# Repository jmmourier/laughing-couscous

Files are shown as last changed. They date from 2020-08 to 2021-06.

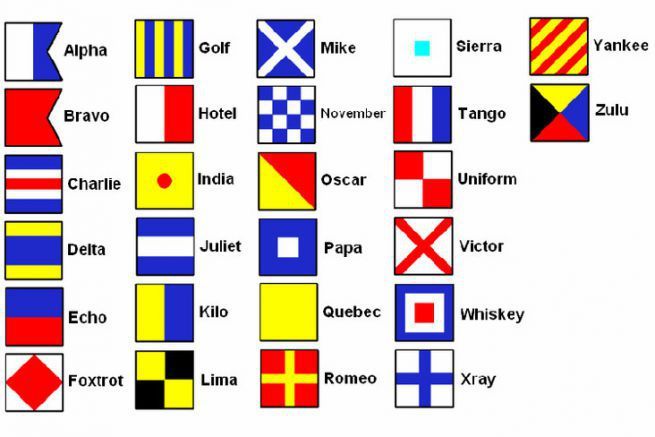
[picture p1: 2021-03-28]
documents/ima-pavillon-alphabet-27640.jpg

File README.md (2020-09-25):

# laughing-couscous

## Presentation   
Couscous is the robot to participate to the eurobot competition.

## Competition  
The robot evolve in a 3 by 2 m environment and perform several action including navigation, detection, recognition and action.
more info about the competition :   
[official website](https://www.eurobot.org/)  
[official rules](https://www.eurobot.org/images/2020/Eurobot2020_Rules_Cup_OFFICIAL_FR.pdf)  

## Team  

## More info
please visit the [wiki](https://github.com/jmmourier/laughing-couscous/wiki) for more info.

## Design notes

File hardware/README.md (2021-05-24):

# Hardware

Pin connections on pro micro : 

                  USB   
            ┌─────────────┐
    MD25 RX │TX        RAW│
    MD25 TX │RX        GND│
            │GND     RESET│
            │GND       VCC│
     I2C US │2-SDA      A3│
     I2C US │3-SCL      A2│
    Grabber │4          A1│
       Flag │5          A0│
            │6          15│
   Select 1 │7          14│Start button
            │8          16│Led R (HS)
   Select 3 │9          10│Led G
            └─────────────┘

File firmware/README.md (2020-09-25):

# Firmware

## introduction
The firmware is running on arduino pro micro.  

## compile and deploy 
using the arduino cli tool :  

    ./arduino-cli compile --fqbn arduino:avr:leonardo myProject
    ./arduino-cli upload -p /dev/ttyACM0 --fqbn arduino:avr:leonardo myProject --log-level debug -v

more info on the [wiki](https://github.com/jmmourier/laughing-couscous/wiki/%5BTools%5D-Flashing-arduino)

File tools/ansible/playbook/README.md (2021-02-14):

# Intro

The goal of this document is to explain in detail every step to be able to deploy on the Raspberry pi zero.

Cross-compile has been added on a previous PR that provides an easy way between x86/ARM compilation. With that we can use Ansible to easily compile C++ sources, build the front end and deploy the result on the target. Ansible is obviously optional, every step described here can be one manually.

Ansible has been added to the docker file which means that every tool needed are now included in the image and no external dependency is required.

# Docker

if you haven't done it yet, make sure to build the docker image using the docker-compose.yml file (from `tools/docker` folder)

```
docker-compose up --build
```

# Connection

Using an other terminal use the following command to get inside the created container:

```
docker exec -it laughing-couscous /bin/bash
```

try to connect to your Raspberry pi with
`ssh pi@192.X.X.X`
If you can connect then you're good to go for the next steps.

# Setting the environment before deploying to the target

This step has be done the first time only. It will generate a file with your credential (make sure they are not sooooo secret). Still using the terminal inside the docker, execute the following command with your credentials from `ansible/` folder:

```
ansible-playbook playbook/setup_env.yml --extra-vars "PI_USERNAME=pi PI_IP=192.168.1.6 PI_PORT=22 PI_SSH_PASSWORD=raspberry"
```

# Last step, building sources and push the result on the target (Back AND front)

```
ansible-playbook playbook/build_and_run.yml
```

if you just want to compile and push the back side run:

```
ansible-playbook playbook/build_back_and_run.yml
```

DONE! Now open a browser and enter the Raspberry pi IP address.
Cheers

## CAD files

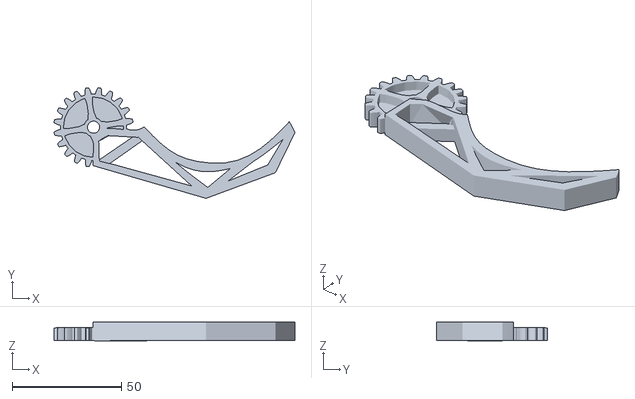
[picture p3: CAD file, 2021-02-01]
hardware/grabber/pinca4_v-2.stl
110.4 x 50.7 x 8.49

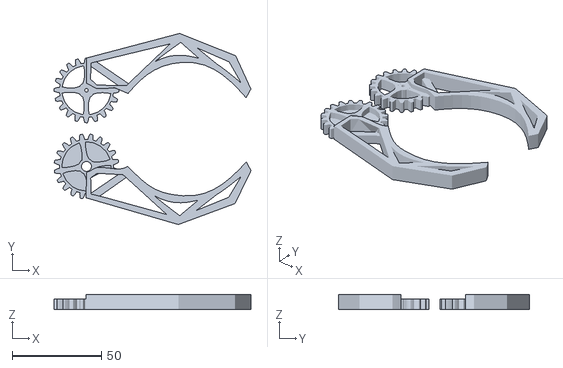
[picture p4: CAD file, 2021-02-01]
hardware/grabber/pinca4_v.STL
110.5 x 107.2 x 8.49

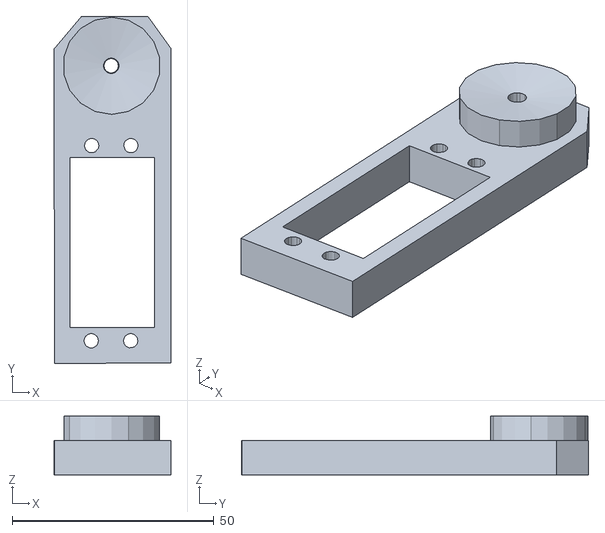
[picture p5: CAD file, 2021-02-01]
hardware/grabber/pincaServ1.STL
28.9 x 85.9 x 14.6

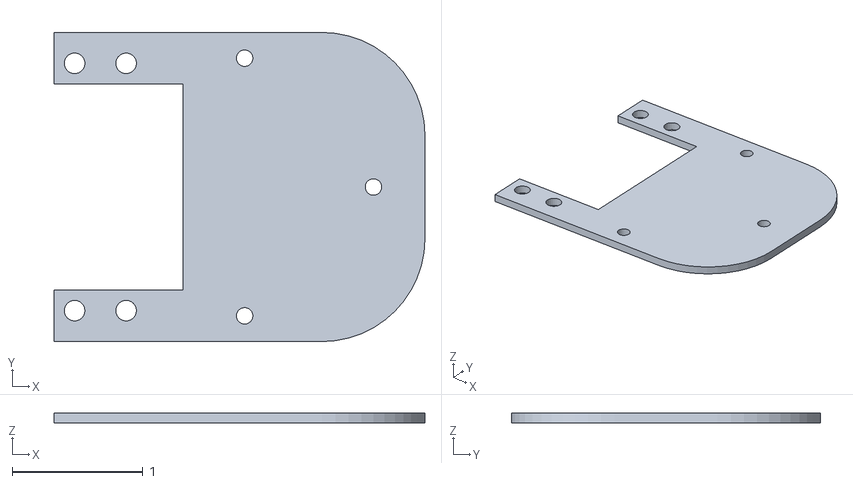
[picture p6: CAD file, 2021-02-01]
hardware/grabber/supportservomoteur1.stl
2.83 x 2.36 x 0.0787

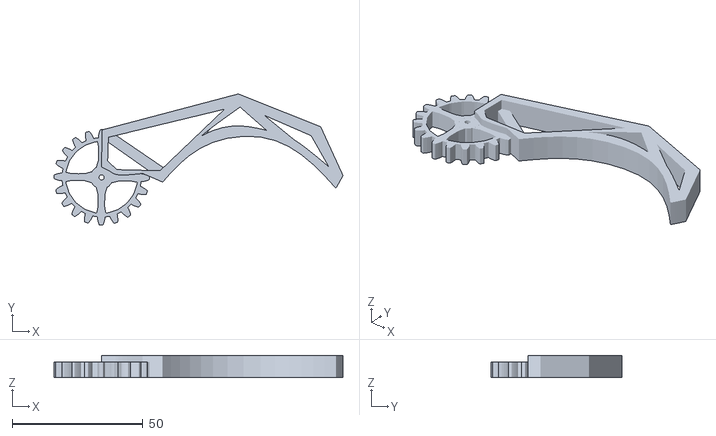
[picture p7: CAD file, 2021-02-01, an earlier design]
hardware/grabber/pinca4_v-1.stl
110.5 x 50.1 x 8.49

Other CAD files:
hardware/grabber/supportservomoteur1.skp

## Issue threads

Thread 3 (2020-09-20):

perhaps useless brackets

devkgs, 2020-09-20:
In Hali.h, line 16,
    virtual int getBatteryVoltage() {};

Why are { and } prensent?

Best wishes

jmmourier, 2020-09-20:
definitly useless, it's a residu when Hali was not the interface but the HalReal implementation, I will remove it next time.

jmmourier, 2020-09-22:
fixed

jmmourier, 2020-09-22:
Fixed

Closed 2020-09-22.

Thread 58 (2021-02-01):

encoder goes negative in forward and backward

devkgs, 2021-02-01:
[RobotController]robot controller callback onClientRequestSetSpeed1 1
encoder1:0 encoder2:0 posX:1 posY:1 angle:0
encoder1:-44 encoder2:-44 posX:0.923206 posY:1 angle:0
encoder1:-170 encoder2:-170 posX:0.703294 posY:1 angle:0

same when speed is -1, -1

jmmourier, 2021-02-01:
Let me check that on the real robot and I fix it

devkgs, 2021-02-09:
Question about arguments of setMd25Speed.

 setMd25Speed(speed_1, speed_2) :
- stop=127
- forward= values>127
- backward= values < 127

?

Closed 2021-02-13.

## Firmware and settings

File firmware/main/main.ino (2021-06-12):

#include "Flag/Flag.cpp"
#include "GameTimer/GameTimer.cpp"
#include "Grabber/Grabber.cpp"
#include "Leds/Leds.cpp"
#include "Md25/Md25.cpp"
#include "MessageParser/MessageParser.cpp"
#include "Switches/Switches.cpp"
#include "Srf02/Srf02.cpp"

int pin_grabber_ = 4;
Grabber grabber_(pin_grabber_);
unsigned long grabber_last_update_ = 0;
unsigned int grabber_timer_ = 300;  // ms

MessageParser message_parser_;
const int buffer_size = 80;
char buffer_[buffer_size];
int buffer_fullfillness = 0;

md25 md25_(Serial1);
unsigned long md25_last_update_ = 0;
unsigned int md25_timer_ = 300;  // ms

int pin_flag_ = 5;
Flag flag_(pin_flag_);
bool is_flag_up_ = false;
unsigned long flag_check_last_update_ = 0;
unsigned long flag_check_timer_ = 300;

int pin_switch_1_ = 7;
int pin_switch_2_ = 9;
Switches switches_(pin_switch_1_, pin_switch_2_);
unsigned long switches_last_update_ = 0;
unsigned long switches_timer_ = 300;

int pin_led_green_ = 10;
int pin_led_red_ = 16;
Leds leds_(pin_led_green_, pin_led_red_);
unsigned long leds_last_update_ = 0;
unsigned long leds_timer_ = 30;

GameTimer game_timer_;
bool is_game_finished = false;
unsigned long is_game_finished_last_update_ = 0;
unsigned long is_game_finished_timer_ = 300;

int pin_start_switch_ = 14;
unsigned long start_switch_last_update_ = 0;
unsigned long start_switch_timer_ = 100;

Srf02 srf02_;
unsigned long srf02_last_update_ = 0;
unsigned long srf02_timer_ = 30;
unsigned long srf02_send_value_last_update_ = 0;
unsigned long srf02_send_value_timer_ = 100;
bool obstacle_detected = false;


void setup() {
    Serial1.begin(38400);
    Serial.begin(9600);

    md25_.setMode(0);
    md25_.setAcceleration(2);
    md25_.resetEncoder();

    grabber_.init();
    delay(10);
    grabber_.open();

    flag_.init();
    delay(10);
    flag_.setFlag(flagDown);

    pinMode(pin_start_switch_,INPUT);

    leds_.setStatus(waiting);

    srf02_.init();
}

void loop() {

    readSerial();

    updateMd25();

    updateGrabber();

    updateFlag();

    checkStartButtonAndSendStatus();

    updateEndGame();

    checkSwitchesAndSendStatus();

    updateLeds();

    srf02Update();

}

void readSerial() {
    if (Serial.available()) {
        unsigned char input_char = Serial.read();
        buffer_[buffer_fullfillness] = input_char;
        buffer_fullfillness++;
        if (buffer_fullfillness >= buffer_size) {
            memset(buffer_, 0, sizeof(buffer_));
            buffer_fullfillness = 0;
        }
        if (input_char == message_parser_.getEndChar()) {
            CommandData command_data = message_parser_.parse(buffer_);
            HandleCommands(command_data);
            memset(buffer_, 0, sizeof(buffer_));
            buffer_fullfillness = 0;
        }
    }
}

void HandleCommands(CommandData command_data) {
    if (command_data.command_ == speedMotor1 &&
        is_game_finished == false &&
        obstacle_detected == false) {
        md25_.setSpeed(motor1, command_data.argument_);
    } else if (command_data.command_ == speedMotor2 &&
        is_game_finished == false && 
        obstacle_detected == false) {
        md25_.setSpeed(motor2, command_data.argument_);
    } else if (command_data.command_ == versionRevisionRequested) {
        md25_.updateRevision();
        delay(10);
        Serial.print("md25version:");
        Serial.print(md25_.getRevision());
        Serial.println(";");
    } else if (command_data.command_ == resetEncoder) {
        md25_.resetEncoder();
        delay(10);
    } else if (command_data.command_ == grabberPositionRequested &&
        is_game_finished == false) {
        if (command_data.argument_ == grabberOpened) {
            grabber_.open();
        } else if (command_data.argument_ == grabberClosed) {
            grabber_.close();
        }
    }
}

void updateMd25(){
    if (millis() - md25_last_update_ > md25_timer_) {
        md25_.updateElectricalData();
        delay(10);
        md25_.updateEncorder();
        delay(10);
        Serial.print("md25voltage:");
        Serial.print(md25_.getVoltage());
        Serial.println(";");
        Serial.print("md25encoder1:");
        Serial.print(md25_.getEncoder(motor1));
        Serial.println(";");
        Serial.print("md25encoder2:");
        Serial.print(md25_.getEncoder(motor2));
        Serial.println(";");
        md25_last_update_ = millis();
    }
}

void updateGrabber(){
    if (millis() - grabber_last_update_ > grabber_timer_) {
        Serial.print("grabberState:");
        Serial.print(grabber_.getGrabber());
        Serial.println(";");
        grabber_last_update_ = millis();
    }
}

void updateFlag(){
    if(millis()- flag_check_last_update_ > flag_check_timer_) {
        if(game_timer_.hasTimerReached(95000)){
            flag_.setFlag(flagUp);
        }
        else{
            flag_.setFlag(flagDown);
        }
        flag_check_last_update_ = millis();
    }
}

void updateEndGame(){
    if (millis() - is_game_finished_last_update_ > is_game_finished_timer_) {
        if(game_timer_.hasTimerReached(100000)){
            md25_.setSpeed(motor1, 128);
            md25_.setSpeed(motor2, 128);
            is_game_finished = true;
            leds_.setStatus(done);
        }
        is_game_finished_last_update_ = millis();
    }
}

void checkStartButtonAndSendStatus(){
    if (millis() - start_switch_last_update_ > start_switch_timer_) {
        
        bool robot_is_started = digitalRead(pin_start_switch_);

        if(robot_is_started){ // started
            if(!game_timer_.isTimerCounting()){
                game_timer_.start();
                leds_.setStatus(running);
            }
        } else { // not started
            game_timer_.reset();
            leds_.setStatus(waiting);
            is_game_finished = false;
        }
        
        Serial.print("robotStarted:");
        Serial.print(robot_is_started);
        Serial.println(";");

        start_switch_last_update_ = millis();
    }
}

void checkSwitchesAndSendStatus(){
    if (millis() - switches_last_update_ > switches_timer_) {
        
        switches_.updateSwitches();

        Serial.print("switch1:");
        Serial.print(switches_.getSwitch(switch_id_1));
        Serial.println(";");

        Serial.print("switch2:");
        Serial.print(switches_.getSwitch(switch_id_2));
        Serial.println(";");

        switches_last_update_ = millis();
    }
}

void updateLeds(){
    if (millis() - leds_last_update_ > leds_timer_) {
        leds_.updateLeds();
        leds_last_update_ = millis();
    }
}

void srf02Update(){
    if (millis() - srf02_last_update_ > srf02_timer_) {
        srf02_.updateSensor();
        srf02_last_update_ = millis();
    }
    int distance = srf02_.getDistance(); 
    if ( distance <= 30 && distance != 0)
    {
        obstacle_detected = true;
        md25_.setSpeed(motor1, 128);
        md25_.setSpeed(motor2, 128);
    }
    else 
    {
        obstacle_detected = false;
    }
    
    if (millis() - srf02_send_value_last_update_ > srf02_send_value_timer_) {
        Serial.print("distance:");
        Serial.print(srf02_.getDistance());
        Serial.println(";");
        srf02_send_value_last_update_ = millis();
    }
}

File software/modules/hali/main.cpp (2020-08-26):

#include <iostream>

#include "Serial.h"
#include "MessageParser.h"

int serialReaderByLine(){
    try {

        Serial serial("/dev/ttyACM0",9600);

        serial.writeString("Hello world\n");
        while(true){
        std::cout<<serial.readLine()<<std::endl;
        }

    } catch(boost::system::system_error& e)
    {
        std::cout<<"Error: "<<e.what()<<std::endl;
        return 1;
    }
}

int serialReaderByChar(){

    try {

        Serial serial("/dev/ttyACM0",9600);

        while(true){
        std::cout<<serial.readChar();
        }

    } catch(boost::system::system_error& e)
    {
        std::cout<<"Error: "<<e.what()<<std::endl;
        return 1;
    }
}

int testParser(){
    MessageParser myParser;
    myParser.addCharToBuffer('a');
    myParser.addCharToBuffer(':');
    myParser.addCharToBuffer(':');
    myParser.addCharToBuffer('b');
    myParser.addCharToBuffer('c');
    myParser.addCharToBuffer(';');

    myParser.addCharToBuffer('a');
    myParser.addCharToBuffer(';');

    myParser.addCharToBuffer(';');

    myParser.addCharToBuffer('a');
    myParser.addCharToBuffer('b');
    myParser.addCharToBuffer(':');
    myParser.addCharToBuffer(':');
    myParser.addCharToBuffer(';');

    myParser.addCharToBuffer(':');
    myParser.addCharToBuffer('a');
    myParser.addCharToBuffer(';');

    myParser.addCharToBuffer('a');
    myParser.addCharToBuffer(';');

    myParser.addCharToBuffer('a');
    myParser.addCharToBuffer(':');
    myParser.addCharToBuffer('b');
    myParser.addCharToBuffer(';');

    myParser.addCharToBuffer('a');
    myParser.addCharToBuffer(':');
    myParser.addCharToBuffer('b');
    myParser.addCharToBuffer(':');
    myParser.addCharToBuffer('c');
    myParser.addCharToBuffer(';');
    
    myParser.addCharToBuffer(':');
    myParser.addCharToBuffer('b');
    myParser.addCharToBuffer(':');
    myParser.addCharToBuffer('c');
    myParser.addCharToBuffer(';');

    myParser.addCharToBuffer('a');
    myParser.addCharToBuffer(':');
    myParser.addCharToBuffer(';');
    myParser.addCharToBuffer('a');
    myParser.addCharToBuffer(':');
    myParser.addCharToBuffer(':');
    myParser.addCharToBuffer(';');

    myParser.addCharToBuffer('a');
    myParser.addCharToBuffer(':');
    myParser.addCharToBuffer(':');
    myParser.addCharToBuffer('b');
    myParser.addCharToBuffer(';');

    myParser.printBuffer();
    myParser.analyseBuffer().print();
    myParser.printBuffer();
    myParser.analyseBuffer().print();
    myParser.printBuffer();
    myParser.analyseBuffer().print();
    myParser.printBuffer();
    myParser.analyseBuffer().print();
    myParser.printBuffer();
    myParser.analyseBuffer().print();
    myParser.printBuffer();
    myParser.analyseBuffer().print();
    myParser.printBuffer();
    myParser.analyseBuffer().print();
    myParser.printBuffer();
    myParser.analyseBuffer().print();
    myParser.printBuffer();
    myParser.analyseBuffer().print();
    myParser.printBuffer();
    myParser.analyseBuffer().print();
    myParser.printBuffer();
    myParser.analyseBuffer().print();
    myParser.printBuffer();
    myParser.analyseBuffer().print();
    return 0;
}

int testParseSerial(){

    MessageParser myParser;
    Serial serial("/dev/ttyACM0",9600);
    while(true){
        try
        {
    myParser.addCharToBuffer(serial.readChar());
    myParser.analyseBuffer().print();
        }
        catch(boost::system::system_error& e)
        {
            //std::cout<<"Error: "<<e.what()<<std::endl;
        }
    }
    return 0;
}

int main(int argc, char* argv[])
{
   return testParseSerial();
}

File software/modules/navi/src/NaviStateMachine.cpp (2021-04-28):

#include "NaviStateMachine.h"

#include <iostream>

#include "logger/LoggerFactory.h"

//#define WHEEL_SPEED 1.0
//#define ROTATION_SPEED 10.0

#define WHEEL_SPEED_BASE 10   // 127
#define WHEEL_SPEED_STOP 128  // 127
#define WHEEL_SPEED_FW WHEEL_SPEED_STOP + WHEEL_SPEED_BASE
#define WHEEL_SPEED_BW WHEEL_SPEED_STOP - WHEEL_SPEED_BASE

void NaviStateMachine::registerNaviSMRequestListener(
    const std::weak_ptr<INaviRequestListener> &navi_listener) {
    navi_listeners_.push_back(navi_listener);
}

void NaviStateMachine::publishToNaviSpeedRequestListeners(const int &motor1, const int &motor2)
    const {
    for (auto const &navi_listener_ptr : navi_listeners_) {
        if (auto navi_listener = navi_listener_ptr.lock()) {
            navi_listener->onNaviSpeedRequest(motor1, motor2);
        }
    }
}

void NaviStateMachine::publishToNaviTargetReachedListeners(void) const {
    for (auto const &navi_listener_ptr : navi_listeners_) {
        if (auto navi_listener = navi_listener_ptr.lock()) {
            navi_listener->onNaviTargetReachedRequest();
        }
    }
}

/**
 * Start rotation to be aligned to the target
 * @param robot_pos
 * @param target_pos
 * @param on_set_speed_callback
 * @return
 */
NaviStateMachine::NaviStateMachineEnum NaviStateMachine::startAlignToTarget(
    pos_info robot_pos,
    pos_info target_pos) {
    /*   std::cout << "navi_state_machine -1-: start rotation: "
                 << getReferenceAngleToTarget(robot_pos, target_pos)
                 << " delta_angle=" << getAngleToTarget(robot_pos, target_pos) << std::endl;
   */
    double delta_angle_from_robot_orientation_to_target_point =
        shortcut_getAngleToTarget(robot_pos, target_pos);
    std::cout << "naviSTM -1-  angle to target: "
              << delta_angle_from_robot_orientation_to_target_point << std::endl;

    if (delta_angle_from_robot_orientation_to_target_point == 0) {
        return NaviStateMachineEnum::ST4_START_FW_MOVEMENT;
    }
    if (getRotationDir(robot_pos, target_pos) == rotdir::Clockwise) {
        // rotate clockwise
        std::cout << "rotate clockwise" << std::endl;
        publishToNaviSpeedRequestListeners(WHEEL_SPEED_FW, WHEEL_SPEED_BW);

        //  on_set_speed_callback(0, 0, ROTATION_SPEED);
    } else {
        // rotate anti-clockwise
        std::cout << "rotate anti-clockwise" << std::endl;
        publishToNaviSpeedRequestListeners(WHEEL_SPEED_BW, WHEEL_SPEED_FW);
        // on_set_speed_callback(0, 0, -ROTATION_SPEED);
    }

    previous_angle_to_target_ = shortcut_getAngleToTarget(robot_pos, target_pos);

    return NaviStateMachineEnum::ST2_ALIGN_TO_TARGET;
}

/**
 * Rotate until robot orientation is aligned to the target
 * @param robot_pos
 * @param target_pos
 * @param on_set_speed_callback
 * @return
 */
NaviStateMachine::NaviStateMachineEnum NaviStateMachine::alignToTarget(
    pos_info robot_pos,
    pos_info target_pos) {
    double delta_angle = shortcut_getAngleToTarget(robot_pos, target_pos);
    std::cout << "navi_state_machine -2-: align to target" << std::endl;
    std::cout << "robot angle:" << robot_pos.orientation << " delta angle:"
              << delta_angle
              //  << " target angle : " << get_reference_angle_to_target(robot_pos, target_pos)
              << std::endl;
    if (getRotationDir(robot_pos, target_pos) == rotdir::Clockwise) {
        if (std::abs(delta_angle) < DELTA_ANGLE_TO_STOP_ROTATION_MOVEMENT) {
            publishToNaviSpeedRequestListeners(WHEEL_SPEED_STOP, WHEEL_SPEED_STOP);
            // on_set_speed_callback(0, 0, 0);
            return NaviStateMachineEnum::ST3_WAIT_FOR_MOVMENT;
        }
    } else {
        if (std::abs(delta_angle) < DELTA_ANGLE_TO_STOP_ROTATION_MOVEMENT) {
            publishToNaviSpeedRequestListeners(WHEEL_SPEED_STOP, WHEEL_SPEED_STOP);
            // on_set_speed_callback(0, 0, 0);
            return NaviStateMachineEnum::ST3_WAIT_FOR_MOVMENT;
        }
    }

    // check overshoot
    // if (std::abs(delta_angle) > previous_angle_to_target_) {
    /*    if (((previous_angle_to_target_ > 0) && (delta_angle < 0)) ||
            ((previous_angle_to_target_ > 0) && (delta_angle < 0))) {
            std::cout << "overshoot" << std::endl;
            publishToNaviSpeedRequestListeners(WHEEL_SPEED_STOP, WHEEL_SPEED_STOP);
            return NaviStateMachineEnum::ST3_WAIT_FOR_MOVMENT;
        }
        previous_angle_to_target_ = std::abs(getAngleToTarget(robot_pos, target_pos));
      */
    previous_angle_to_target_ = std::abs(shortcut_getAngleToTarget(robot_pos, target_pos));
    return NaviStateMachineEnum::ST2_ALIGN_TO_TARGET;
}

/**
 *
 * @return
 */
NaviStateMachine::NaviStateMachine::NaviStateMachineEnum NaviStateMachine::waitForMovement() {
    return NaviStateMachineEnum::ST4_START_FW_MOVEMENT;
}

NaviStateMachine::NaviStateMachineEnum NaviStateMachine::startFw(
    pos_info robot_pos,
    pos_info target_pos) {
    std::cout << "navi_state_machine -4-: FW" << std::endl;
    publishToNaviSpeedRequestListeners(WHEEL_SPEED_FW, WHEEL_SPEED_FW);
    // on_set_speed_callback(WHEEL_SPEED, 0, 0);
    previous_distance_to_target_ = getDistanceToTarget(robot_pos, target_pos);
    return NaviStateMachineEnum::ST5_DRIVING_TO_TARGET;
}

NaviStateMachine::NaviStateMachineEnum NaviStateMachine::drivingToTarget(
    pos_info robot_pos,
    pos_info target_pos) {
    std::cout << "navi_state_machine -5-: driving" << std::endl;
    if (getDistanceToTarget(robot_pos, target_pos) < DELTA_DIST_TO_STOP_FW_MOVEMENT) {
        publishToNaviSpeedRequestListeners(WHEEL_SPEED_STOP, WHEEL_SPEED_STOP);
        // on_set_speed_callback(0, 0, 0);
        return NaviStateMachineEnum::ST9_DONE;
    }

    // check overshoot
    if (previous_distance_to_target_ < getDistanceToTarget(robot_pos, target_pos)) {
        publishToNaviSpeedRequestListeners(WHEEL_SPEED_STOP, WHEEL_SPEED_STOP);
        return NaviStateMachineEnum::ST9_DONE;
    }
    previous_distance_to_target_ = getDistanceToTarget(robot_pos, target_pos);
    return NaviStateMachineEnum::ST5_DRIVING_TO_TARGET;
}

NaviStateMachine::NaviStateMachineEnum NaviStateMachine::done() {
    publishToNaviSpeedRequestListeners(WHEEL_SPEED_STOP, WHEEL_SPEED_STOP);
    publishToNaviTargetReachedListeners();
    // on_set_speed_callback(0, 0, 0);
    // exit(0);
    return NaviStateMachineEnum::ST0_IDLE;
}

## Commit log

2020-08-16 [Software][hali] update CMakelist to compile on raspberry pi
2020-08-29 [Firmware] add test for md25 board
2020-09-01 [firmware] add library for md25 board
2020-09-05 [Tools] add arduino command line interface installer
2020-09-05 [Firmware] use symbolic link for libraries structure to avoid duplication
    [testmd25Library.ino]
2020-09-05 [Software][hali] rework hali interface to cleanup
    [Hali.cpp, main.cpp]
2020-09-06 [Software][hali] add hash to use switch in parser
2020-09-06 [Software][hali] add display of encoder
2020-09-06 [Firmware] update and send encoder values
2020-09-06 [Software][hali] add condition to make wheels turning
2020-09-06 [Firmware] add new line for printing what is received
2020-09-07 [Software][hali] fix convention for variables
    [HalReal.cpp, HalSimu.cpp, HalSimu.h]
2020-09-07 [Software][hali] add simulation of the encoder based on speed
2020-09-14 [Firmware] fix typo in include
    [testmd25Library.ino]
2020-09-14 [Firmware] with wrong variable name
    [main.ino]
2020-09-14 [Firmware] fix wrong println
    [main.ino]
2020-09-14 [Software][hali] print buffer before clean and add try catch for read
2020-09-22 Update Hali.h
    [Software][hali] remove useless brackets
2020-09-25 Add grpc to cmake files with a procedure that will generate cpp classes from sample robot.proto file
2020-09-27 [Software][moti] add main method to convert base speed to motor speed
2020-09-27 [Software][moti] fix unit, fix wrong variable for calculus, add main for test
    [Moti.cpp, main.cpp]
2020-09-27 [posi module] complete posi test on updatePosition method using fake timer
2020-09-27 [Firmware] fix missing call of function
    [main.ino]
2020-09-27 [Firmware] reset encoder when starting
    [main.ino]
2020-09-29 [posi module] fix bug in abs position calcul (wrong units)
    [Posi.cpp]
2020-09-29 [posi module] now keeps previous encoder values to calculate new abs position
2020-10-04 [posi module] fix bug unit conversion
    [Posi.cpp]
2020-10-04 [gui] remove sample grpc service and create grpc position service
2020-10-09 add raspberry tools
2020-10-11 [script] add script to build boost for arm version
2020-10-11 [script] add setup arm file to set env ready for cross compiling
2020-10-13 [gui] add material io dependency
2020-12-15 [UI] add material icons to nodejs dependencies
2021-01-22 Removed submodule raspberry-tools
2021-01-22 [docker] create a toolchain cmake file directly in the image and build arm pi tools for pre cross-compile
2021-02-01 [Hardware] add grabber stl files
    [pinca4_v-1.stl, pinca4_v-2.stl, pinca4_v.STL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]
2021-02-25 [UI front] remove heavy "Material UI" lib from project. The design has been improved and now the main package manager is yarn and not npm anymore
2021-03-24 [posi] replace parameters x,y,orientation with new PositionOrientation struct
    [CouscousManager.cpp, Posi.cpp, main.cpp]
2021-03-24 [webserver] replace parameters x,y,orientation with new PositionOrientation struct
    [CouscousManager.cpp]
2021-03-24 [posi] fix bug with position
    [CouscousManager.cpp, Posi.cpp, main.cpp]
2021-03-28 [UI/Posi] inverse rotation and change 0,0 reference point to bottom left corner on UI front - add stop button
2021-03-30 [Hali/Couscous] Remove Hali listener, Couscous app now gets encoders and update posi
2021-03-30 [Soft][hali] update simu zero value for motor control and ratio speed time
2021-04-10 [Firmware] fix typo in main
    [main.ino]
2021-04-10 [Firmware] fix naming in message parser
    [testMessageParserLibrary.ino]
2021-04-10 [Firmware] add lib to control Leds
2021-04-10 [Firmware] add lib to read switches
2021-04-10 [Soft][hali] add switches, robot_started, and obstacle
2021-04-28 [posi] fix position to absolute between 0 and 2 * PI
    [Posi.cpp, constant.h]
2021-04-28 [Software][Navi] add regulator
2021-05-13 [UI front] add orientation button and adapt api proto file
2021-05-13 [Firmware] add command to reset encoder
    [main.ino]
2021-05-13 [Soft][hali] add reset encoder at start
    [HalReal.cpp]
2021-05-16 [Hardware] add connection info on arduino
2021-05-23 [UI front] Remove info panel, add info within area with new battery
2021-05-24 [webserver] stream battery along robot position
2021-05-24 fix what shouldn't have been merged
    [CouscousManager.cpp]
2021-05-30 [hali] fix hali tests
    [main.cpp]
2021-05-30 [Couscous] load correct version of hali
    [main.cpp]
2021-06-13 [UI back] add robotState change with current action
2021-06-13 [UI Front] a current action info in arena
2021-06-18 [docker] add multi stages to dockerfile to build a lighter image
2021-06-18 [webserver] send battery to front
2021-06-18 fix grabber on state change notify missi
    [CouscousManager.cpp]
